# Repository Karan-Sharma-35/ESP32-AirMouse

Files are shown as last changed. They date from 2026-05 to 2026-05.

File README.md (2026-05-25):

# Esp32 AirMouse Project

### Equipment:
- ESP32 microcontroller
- Joystick Shield

### Software:
- Arduino IDE

### Description:
With the use of the the bluetooth and wifi capabilities of the ESP32, I plan to use a regular joystick shield to make a working AirMouse that can be used wherever I go. The AirMouse should be able to also handle mouse button 4 and mouse button 5 setup that a lot of modern mice have. I have also added functionality to allow the user to change the AirMouse's sensitivity.

### Progress:
Hardware testing is completed, there will be a demo video for the prototype. Currently designing the PCB for the board to shed reliability of the breadboard and reduce space it consumes to match the housing, as shown in the STL files.

### Circuit Design/Diagram:
Prototype Circuit diagram

### Prototype Test Video:
https://github.com/user-attachments/assets/bc51f338-7813-4573-9226-b972f68b9daf

### Updated Circuit Schematic (Made using a software instead of being hand drawn):


### Final PCB Desgin


### Sources used so far:
- https://protosupplies.com/wp-content/uploads/2018/07/Funduino-Joystick-Shield-Connections.jpg
joystick pinouts
- https://www.youtube.com/watch?v=CD8VJl27n94
- https://github.com/T-vK/ESP32-BLE-Mouse

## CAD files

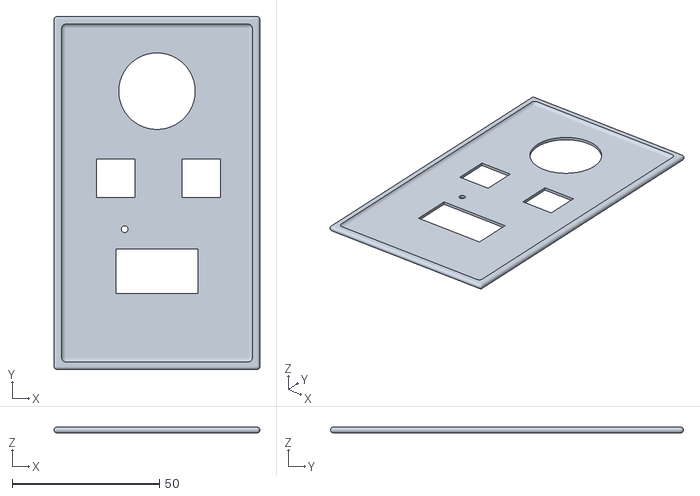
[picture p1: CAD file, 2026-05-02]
STL models/lid.stl
70.0 x 120.0 x 2.00

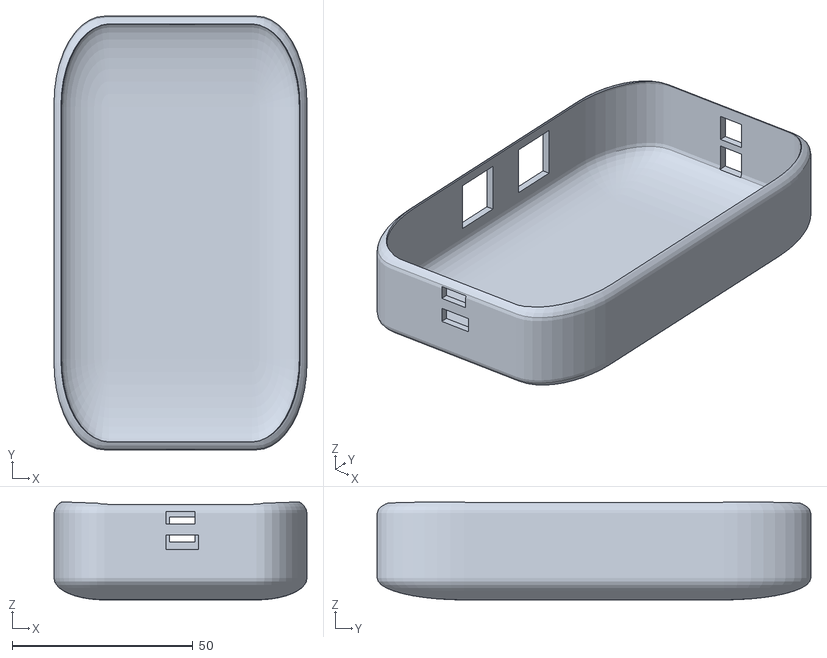
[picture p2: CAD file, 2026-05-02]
STL models/tub.stl
70.0 x 120.0 x 27.1

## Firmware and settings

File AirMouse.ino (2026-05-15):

#include <BleConnectionStatus.h>
#include <BleMouse.h>
#include <BLEDevice.h>
#include <Wire.h>
#include <Adafruit_GFX.h>
#include <Adafruit_SSD1306.h>

// Brownout overrides (just in case)
#include "soc/soc.h"
#include "soc/rtc_cntl_reg.h"

BleMouse bleMouse("Frankenstein", "Espressif", 100);

//using hiletgo to connect to the esp32
#include <Arduino.h>
#include <HardwareSerial.h>

//OLED defines
#define SCREEN_WIDTH 128 // OLED display width, in pixels
#define SCREEN_HEIGHT 32 // OLED display height, in pixels
#define OLED_RESET    -1 // This tells the library your screen doesn't have a dedicated reset pin

//Creating the display object
Adafruit_SSD1306 display(SCREEN_WIDTH, SCREEN_HEIGHT, &Wire, OLED_RESET);

//pin definitions

//joystick pins
const int PIN_X = 34; //horizaontal axis
const int PIN_Y = 35; //vertical movement

//the buttons orientation of joystick being at the top
const int PIN_BTN_C = 27; //Green button (MB4/back)
const int PIN_BTN_A = 13; //Blue btn (MB5/forward)
const int PIN_BTN_B = 14; //Red btn (right click)
const int PIN_BTN_D = 26; //Black button (left click)

//small buttons I will use as sensitivity adjusters
const int PIN_BTN_E = 25; //lower button (lower sens)[traditional mouse decrease]
const int PIN_BTN_F = 33; //upper button (increase sens)[traditional mouse increase]

//joystick btn
const int PIN_BTN_K = 32; //joystick button (middle click)

//OLED buttons
/* Green wire goes to Pin 22 and Blue wire goes to Pin 21 */

//Status LED Pin (Usually GPIO 2)
const int STATUS_LED = 2;

//state tracker for the BLE connection
bool wasConnected = false; //default

//mouse code

//config for the "cursor"
const int DEADZONE = 850; //Ignores minor drift
const int CENTERVAL = 1930; //joystick center
int sensitivity = 120; //Higher sens = slower cursor (changed so I can add functionality to change the sens using F and E)

//state tracker for the btns
int lastBtnKState = HIGH; //High meaning that it is unpressed due to INPUT_PULLUP
int lastBtnBState = HIGH; //High meaning that it is unpressed due to INPUT_PULLUP
int lastBtnDState = HIGH; //High meaning that it is unpressed due to INPUT_PULLUP
int lastBtnAState = HIGH; //High meaning that it is unpressed due to INPUT_PULLUP
int lastBtnCState = HIGH; //High meaning that it is unpressed due to INPUT_PULLUP
int lastBtnEState = HIGH; //High meaning that it is unpressed due to INPUT_PULLUP
int lastBtnFState = HIGH; //High meaning that it is unpressed due to INPUT_PULLUP

//void setup cause this is C and void means no data type assignment is needed
void setup(){
  // Disable the brownout detector so the board doesn't crash on BLE startup
  WRITE_PERI_REG(RTC_CNTL_BROWN_OUT_REG, 0);
  Serial.begin(115200);

  pinMode(STATUS_LED, OUTPUT);
  digitalWrite(STATUS_LED, LOW); //Starts off

  //Joystick config
  //Since it is purely analog for now, we can leave it as INPUT
  pinMode(PIN_X, INPUT);
  pinMode(PIN_Y, INPUT);

  //Button config
  pinMode(PIN_BTN_K, INPUT_PULLUP); //since it wires straight to gnd it needs to be INPUT_PULLUP
  pinMode(PIN_BTN_B, INPUT_PULLUP); //since it wires straight to gnd it needs to be INPUT_PULLUP
  pinMode(PIN_BTN_D, INPUT_PULLUP); //since it wires straight to gnd it needs to be INPUT_PULLUP
  pinMode(PIN_BTN_A, INPUT_PULLUP); //since it wires straight to gnd it needs to be INPUT_PULLUP
  pinMode(PIN_BTN_C, INPUT_PULLUP); //since it wires straight to gnd it needs to be INPUT_PULLUP
  pinMode(PIN_BTN_E, INPUT_PULLUP); //since it wires straight to gnd it needs to be INPUT_PULLUP
  pinMode(PIN_BTN_F, INPUT_PULLUP); //since it wires straight to gnd it needs to be INPUT_PULLUP

  // Initialize the OLED display
  if(!display.begin(SSD1306_SWITCHCAPVCC, 0x3C)) { 
    Serial.println(F("OLED failed to initialize"));
    // We don't stop the code here so the mouse still works even if screen fails
  }

  display.clearDisplay();
  display.setTextColor(SSD1306_WHITE);
  display.display(); // Start with a blank screen

  Serial.println("Initiating lightning strike.");
  //just cuz
  Serial.print(".");
  Serial.print(".");
  Serial.print(".");
  Serial.print(".");
  updateDisplay();
  bleMouse.begin();
}

//void loop time for the ESP32 to continually check the inputs
void loop(){

  //connection checker
  bool isConnected = bleMouse.isConnected();//local variable so it is easier to use multiple times

  //When Connection has just been established
  if(isConnected && !wasConnected){
    Serial.println("Frankenstein has risen!");
    digitalWrite(STATUS_LED, HIGH); //updating blue LED
    wasConnected = true; //updating the flag
  }

  //Just diconnected
  else if(!isConnected && wasConnected){
    Serial.println("Frankenstein needs some juice!");
    digitalWrite(STATUS_LED, LOW);

    //Delay to ensure the board has enough time to restart
    delay(500);

    //Restarting the advertising
    BLEDevice::startAdvertising();

    wasConnected = false; //updating the flag
  }

  //LED logic
  if(!isConnected){
    if((millis()/500)%2 == 0){
      digitalWrite(STATUS_LED, HIGH);
    }
    else{
      digitalWrite(STATUS_LED, LOW);
    }
  }

  //mouse code start

  //Joystick logic
  if(bleMouse.isConnected()){

    //movement logic

    //reading the analog signals of the joystick
    int xReadings = analogRead(PIN_X);
    int yReadings = analogRead(PIN_Y);
    int xVal = 0;
    int yVal = 0;

    //Using the deadzone to make the adjustments for drift
    if(abs(xReadings - CENTERVAL) > DEADZONE) {
      xVal = xReadings - CENTERVAL;
    }
    if(abs(yReadings - CENTERVAL) > DEADZONE) {
      yVal = yReadings - CENTERVAL;
    }

    // calculating how far to move the mouse based on sens
    int xMove = xVal/sensitivity;
    int yMove = (yVal/sensitivity);

    //making sure signal is sent only if there is actual movement
    if(xMove != 0 || yMove != 0){
      bleMouse.move(xMove, yMove);
    }

    //middle click logic
    
    //updating state based on the input
    int currBtnKState = digitalRead(PIN_BTN_K);

    //checking if the button state changed after the last loop
    if(currBtnKState != lastBtnKState){

      if(currBtnKState == LOW){
        //LOW shows that the button was pressed
        bleMouse.press(MOUSE_MIDDLE);
        //commented out to prevent serial monitor clutter
        // Serial.println("Middle Click has been Pressed");
      }
      else{
        //meaning it is on high and button has been released
        bleMouse.release(MOUSE_MIDDLE);
        //commented out to prevent serial monitor clutter
        // Serial.println("Middle click has been Released");
      }

      //updating the state to prevent spamming
      lastBtnKState = currBtnKState;

      //adding a delay for consistency
      delay(20);
    }

    //Right click logic
    
    //updating state based on the input
    int currBtnBState = digitalRead(PIN_BTN_B);

    //checking if the button state changed after the last loop
    if(currBtnBState != lastBtnBState){

      if(currBtnBState == LOW){
        //LOW shows that the button was pressed
        bleMouse.press(MOUSE_RIGHT);
        //commented out to prevent serial monitor clutter
        // Serial.println("Right Click has been Pressed");
      }
      else{
        //meaning it is on high and button has been released
        bleMouse.release(MOUSE_RIGHT);
        //commented out to prevent serial monitor clutter
        // Serial.println("Right click has been Released");
      }

      //updating the state to prevent spamming
      lastBtnBState = currBtnBState;

      //adding a delay for consistency
      delay(20);
    }

    //Left click logic
    
    //updating state based on the input
    int currBtnDState = digitalRead(PIN_BTN_D);

    //checking if the button state changed after the last loop
    if(currBtnDState != lastBtnDState){

      if(currBtnDState == LOW){
        //LOW shows that the button was pressed
        bleMouse.press(MOUSE_LEFT);
        //commented out to prevent serial monitor clutter
        // Serial.println("Left Click has been Pressed");
      }
      else{
        //meaning it is on high and button has been released
        bleMouse.release(MOUSE_LEFT);
        //commented out to prevent serial monitor clutter
        // Serial.println("Left click has been Released");
      }

      //updating the state to prevent spamming
      lastBtnDState = currBtnDState;

      //adding a delay for consistency
      delay(20);
    }

    //MB5 click logic
    
    //updating state based on the input
    int currBtnAState = digitalRead(PIN_BTN_A);

    //checking if the button state changed after the last loop
    if(currBtnAState != lastBtnAState){

      if(currBtnAState == LOW){
        //LOW shows that the button was pressed
        bleMouse.press(MOUSE_FORWARD);
        //commented out to prevent serial monitor clutter
        Serial.println("MB5 Click has been Pressed");
      }
      else{
        //meaning it is on high and button has been released
        bleMouse.release(MOUSE_FORWARD);
        //commented out to prevent serial monitor clutter
        Serial.println("MB5 click has been Released");
      }

      //updating the state to prevent spamming
      lastBtnAState = currBtnAState;

      //adding a delay for consistency
      delay(20);
    }

    //MB4 click logic
    
    //updating state based on the input
    int currBtnCState = digitalRead(PIN_BTN_C);

    //checking if the button state changed after the last loop
    if(currBtnCState != lastBtnCState){

      if(currBtnCState == LOW){
        //LOW shows that the button was pressed
        bleMouse.press(MOUSE_BACK);
        //commented out to prevent serial monitor clutter
        Serial.println("MB4 Click has been Pressed");
      }
      else{
        //meaning it is on high and button has been released
        bleMouse.release(MOUSE_BACK);
        //commented out to prevent serial monitor clutter
        Serial.println("MB4 click has been Released");
      }

      //updating the state to prevent spamming
      lastBtnCState = currBtnCState;

      //adding a delay for consistency
      delay(20);
    }

    //Sensitivity increase (in the traditional mouse sense which in code is lower sens)
    
    //updating state based on the input
    int currBtnFState = digitalRead(PIN_BTN_F);

    //checking if the button state changed after the last loop
    if(currBtnFState != lastBtnFState){

      if(currBtnFState == LOW){
        //"increasing the sens by 10"
        sensitivity -= 10;

        //just to make sure we dont go to 0
        if (sensitivity < 10) {
           sensitivity = 10; // Never let it drop below 10!
        }

        //commented out to prevent serial monitor clutter
        // Serial.print("Current Sens (rmb lower num means higher sens): ");
        // Serial.println(sensitivity);
        updateDisplay();
      }

      //updating the state to prevent spamming
      lastBtnFState = currBtnFState;

      //adding a delay for consistency
      delay(20);
    }

    //Sensitivity decrease (in the traditional mouse sense which in code is higher sens)
    
    //updating state based on the input
    int currBtnEState = digitalRead(PIN_BTN_E);

    //checking if the button state changed after the last loop
    if(currBtnEState != lastBtnEState){

      if(currBtnEState == LOW){
        //"increasing the sens by 10"
        sensitivity += 10;

        //so we dont go over a cerain amt
        if (sensitivity > 350) {
           sensitivity = 350; // Never let it go above 350!
        }
        //commented out to prevent serial monitor clutter
        // Serial.print("Current Sens (rmb higher num means lower sens): ");
        // Serial.println(sensitivity);
        updateDisplay();
      }

      //updating the state to prevent spamming
      lastBtnEState = currBtnEState;

      //adding a delay for consistency
      delay(20);
    }

    //delay for stability
    delay(10);
  }
}

void updateDisplay(){

  display.clearDisplay(); //start blank
  display.setTextSize(1); //set small text (can be adjusted based on testing)
  display.setCursor(0,0); //keeping it to the top left
  display.print("Sens:");

  //Calculations for the displayed sensitivity values
  int calculatedSens = map(sensitivity, 350, 10, 400, 3200);

  display.setCursor(0,15); //move down for the actual sensitivity value
  display.setTextSize(2); //increase number size
  display.print(calculatedSens);

  display.display(); //pushing to display everything
}

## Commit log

2026-04-20 Going back to basics on the AirMouse
    Upon further diagnostics and testing, the reason the board was invisible was that it was shorted out and no longer able to use enough power to send out a steady Bluetooth signal.
    [AirMouse.ino]
2026-05-01 Revise README with testing updates and circuit diagram
    Updated the progress section to reflect testing in a real environment and added a circuit diagram.
2026-05-01 All buttons configured and ready to be tested
    Added features include the 2 side mouse buttons that come with most mice, and also sensitivity adjuster buttons
2026-05-02 Including the CAD designs for the housing
    [lid.stl, tub.stl]
2026-05-07 Adjust joystick y axis to no longer be inverted and deadzone settings
    Updated the joystick sensitivity logic and deadzone value.
    [AirMouse.ino]
2026-05-15 OLED Display update
    As the board transitions to the newer circuit with the additions of the new parts and the OLED screen, I updated the code to accommodate the sensitivity/DPI display and the calculation to the traditi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
2026-05-18 Add prototype test video link to README
2026-05-21 Added updated circuit schematic to README
    Added an updated circuit schematic image to the README.
2026-05-25 Gerbers files for the PCB
    [Frankenstein PCB-B_Cu.gbl, Frankenstein PCB-B_Mask.gbs, Frankenstein PCB-B_Paste.gbp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]
2026-05-25 Add final PCB design section to README
    Added final PCB design image to the README.
